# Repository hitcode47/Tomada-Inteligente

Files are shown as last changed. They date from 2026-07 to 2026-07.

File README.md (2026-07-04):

# EcoPlug — Tomada Inteligente

Projeto desenvolvido para a disciplina de **Projeto de Sistemas Embutidos** do Curso de Graduação em Engenharia Elétrica da **Universidade Federal de Minas Gerais (UFMG)**.

---

O consumo de energia elétrica residencial é, em grande parte, invisível ao usuário final: a conta de luz mostra apenas um valor mensal agregado, sem indicar quais aparelhos são responsáveis pela maior parcela do gasto. Essa falta de visibilidade dificulta a identificação de desperdícios e torna quase impossível tomar decisões conscientes sobre o uso da energia — como identificar um aparelho com consumo acima do esperado por mau funcionamento, ou simplesmente entender como hábitos do dia a dia se traduzem em custo.

O **EcoPlug** foi criado para preencher essa lacuna. Trata-se de uma tomada inteligente que, ao ser inserida entre a tomada da parede e o aparelho, passa a medir continuamente tensão, corrente, potência ativa e energia acumulada — com erro inferior a 5%. Esses dados são enviados a cada 5 segundos para um servidor em nuvem e exibidos em tempo real em uma interface web acessível de qualquer dispositivo na rede.

Além do monitoramento, o sistema permite ligar e desligar remotamente a tomada, registra o histórico de consumo por hora, gera gráficos de potência e estimativa de custo em reais, e sinaliza o estado do dispositivo por LEDs indicadores. O protótipo suporta múltiplas tomadas monitoradas simultaneamente e é configurado via portal Wi-Fi, sem necessidade de programação pelo usuário final.

O hardware foi desenvolvido em torno de um ESP32, com o módulo PZEM-004T para medição elétrica, relé para controle do acionamento e um invólucro impresso em 3D. O backend roda em FastAPI com banco de dados PostgreSQL hospedado na Oracle Cloud, e o frontend foi desenvolvido em React.

## Project Model Canvas

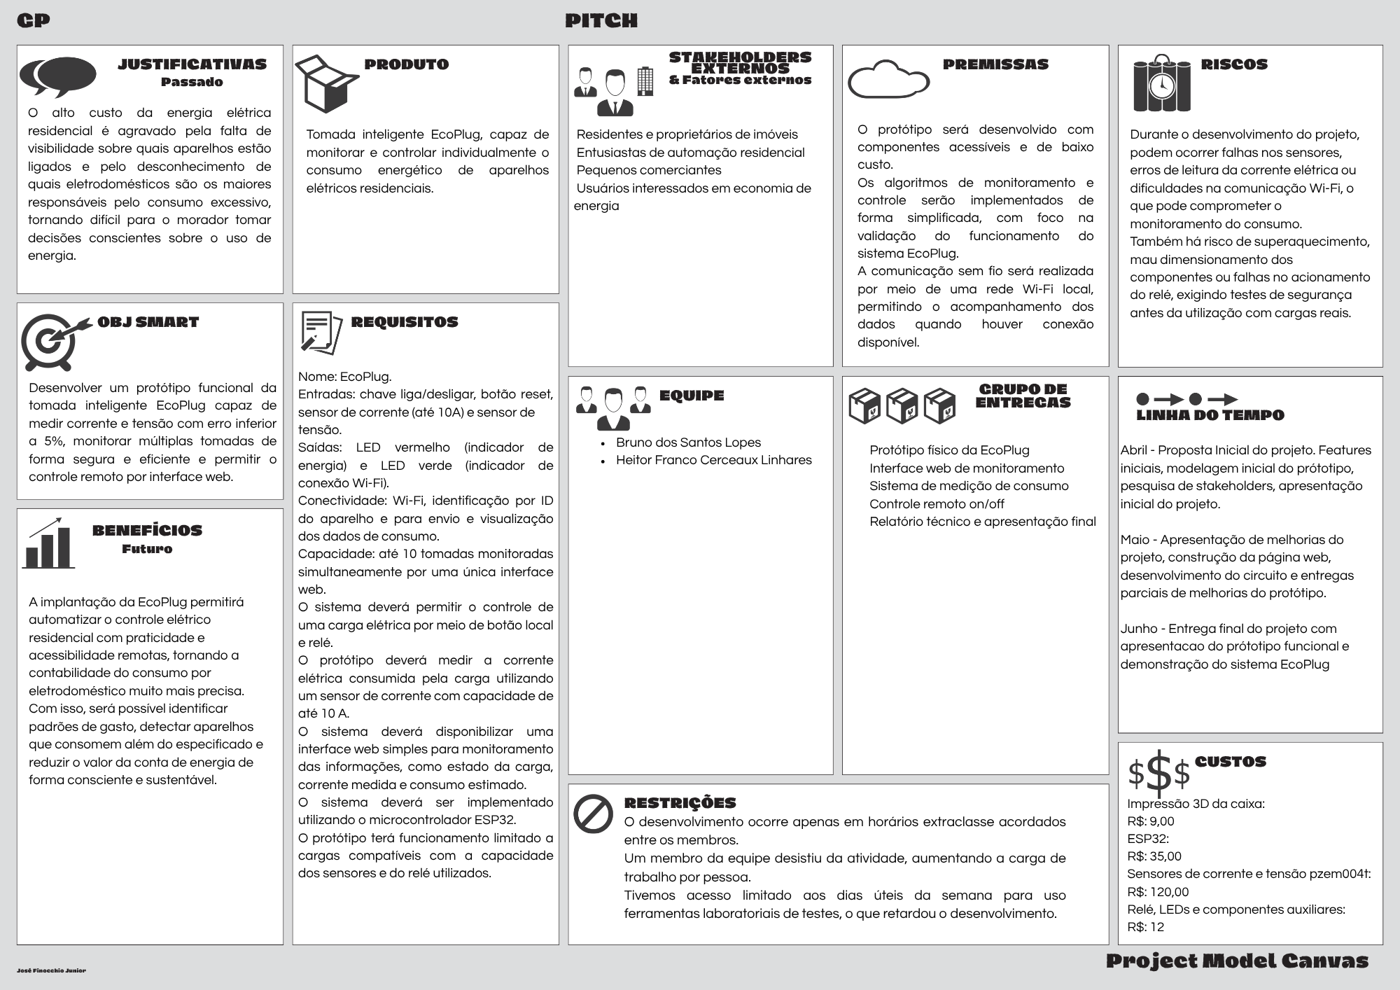
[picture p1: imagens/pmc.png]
Project Model Canvas


## Imagens

| | |
|---|---|
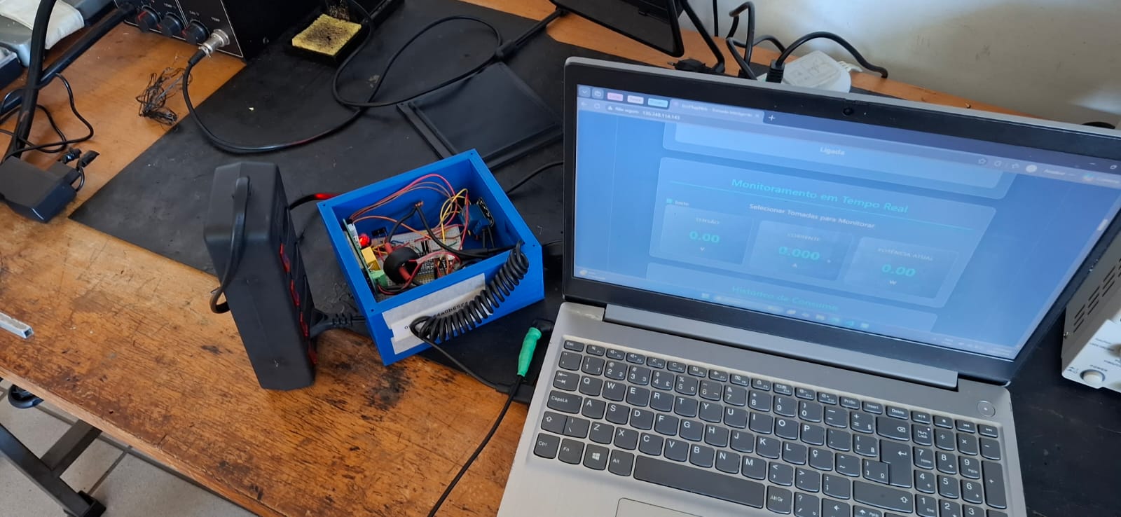
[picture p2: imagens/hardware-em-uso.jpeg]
Hardware em uso
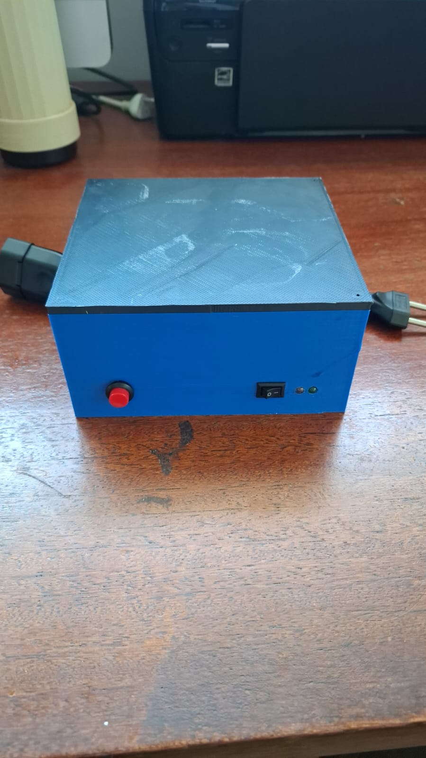
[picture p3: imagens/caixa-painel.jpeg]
Painel frontal
|  |  |
| Protótipo em bancada com dashboard no navegador | Painel frontal: botão de reset, chave e LEDs de status |
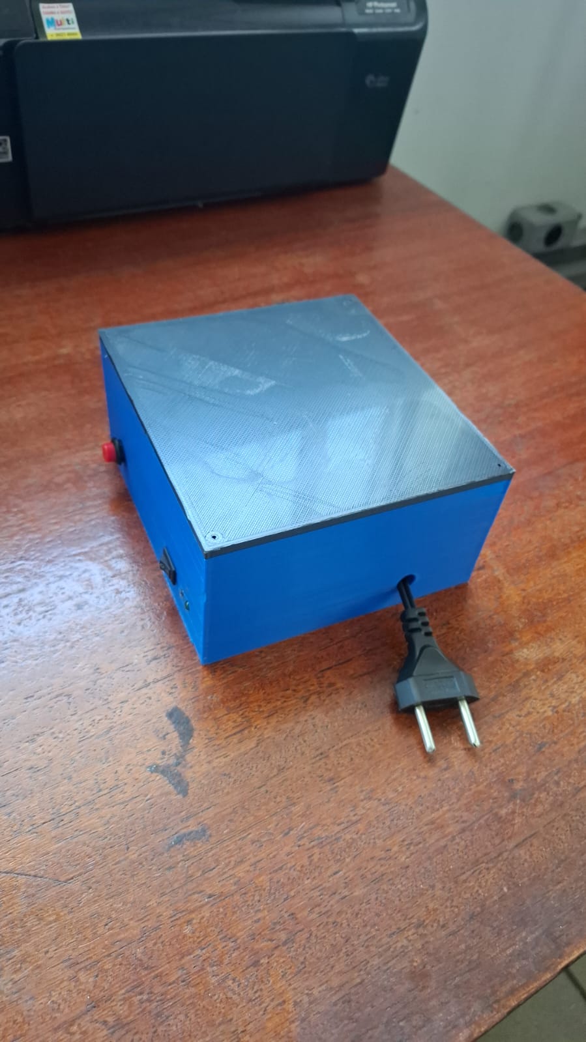
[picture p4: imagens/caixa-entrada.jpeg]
Entrada AC
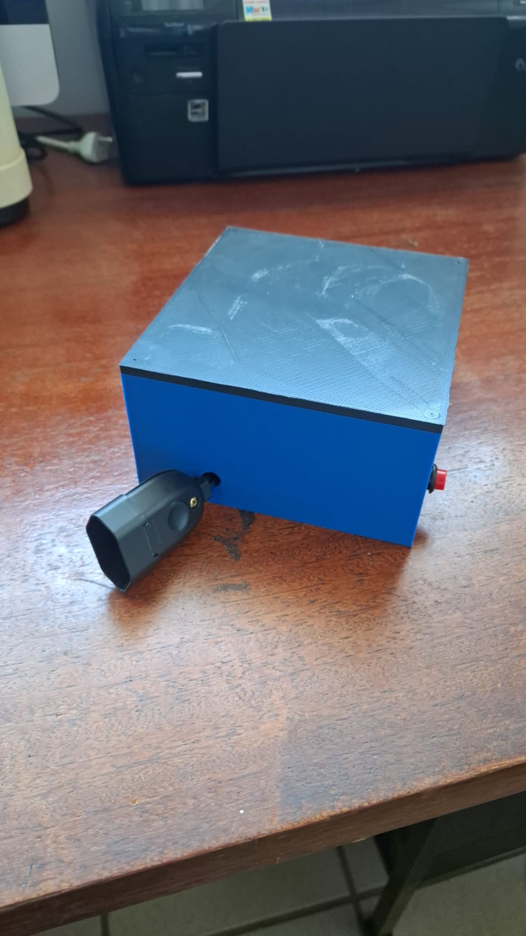
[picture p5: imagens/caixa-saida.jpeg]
Saída AC
|  |  |
| Caixa fechada — entrada de energia (plug macho) | Lateral com tomada de saída (fêmea) |

### Esquemático elétrico

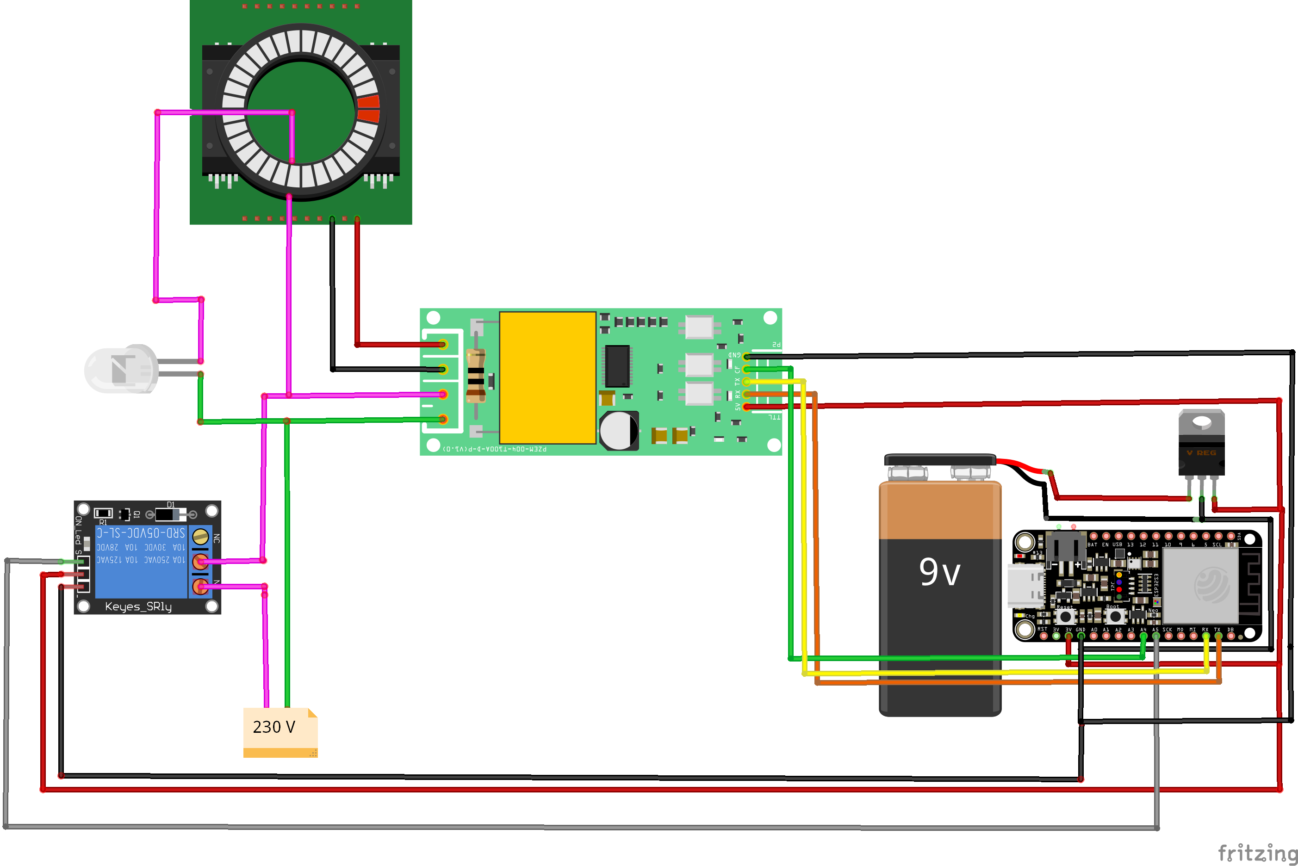
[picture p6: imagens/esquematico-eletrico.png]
Esquemático elétrico


## Arquitetura

```
┌──────────────────────────────────────────────────┐
│              Hardware (ESP32 + PZEM-004T)        │
│   - Mede tensão, corrente, potência, energia     │
│   - WiFi Enterprise (WPA2-EAP / UFMG)           │
│   - Relé NC para controle da tomada             │
└──────────────────┬───────────────────────────────┘
                   │ POST JSON a cada 5s
                   ↓
┌──────────────────────────────────────────────────┐
│         Backend (FastAPI + PostgreSQL)           │
│   - Armazena leituras no banco de dados         │
│   - Autenticação JWT                            │
│   - API REST: energia, dispositivos, gráficos   │
└──────────────────┬───────────────────────────────┘
                   │ GET JSON (polling 5s)
                   ↓
┌──────────────────────────────────────────────────┐
│         Frontend (React + Vite)                  │
│   - Dashboard em tempo real                     │
│   - Gráficos de consumo (potência / custo)      │
│   - Gerenciamento e controle de tomadas         │
└──────────────────────────────────────────────────┘
```

## Estrutura do Projeto

```
Tomada-Inteligente/
├── Backend/
│   ├── main.py                # Servidor FastAPI
│   ├── models.py              # Modelos SQLAlchemy
│   ├── schemas.py             # Schemas Pydantic
│   ├── database.py            # Conexão PostgreSQL
│   ├── security.py            # JWT e autenticação
│   ├── routers/
│   │   ├── auth.py            # Login / registro
│   │   ├── devices.py         # CRUD de dispositivos
│   │   └── energia.py         # Leituras e gráficos
│   ├── requirements.txt
│   └── .env.example
├── Frontend/
│   ├── src/
│   │   ├── components/
│   │   │   ├── Header.jsx
│   │   │   ├── ManagementSection.jsx
│   │   │   ├── ControlSection.jsx
│   │   │   ├── MonitoringSection.jsx
│   │   │   ├── ChartFilterSection.jsx
│   │   │   └── HistorySection.jsx
│   │   ├── pages/
│   │   │   ├── HomePage.jsx
│   │   │   └── LoginPage.jsx
│   │   ├── hooks/
│   │   │   └── useSockets.js
│   │   ├── services/
│   │   │   ├── socketService.js
│   │   │   └── authService.js
│   │   ├── config.js
│   │   ├── App.jsx
│   │   └── main.jsx
│   ├── .env.production
│   ├── package.json
│   └── vite.config.js
├── hardware/
│   └── controle.ino           # Firmware ESP32
├── imagens/                   # Screenshots e fotos do hardware
└── README.md
```

## Hardware

| Componente | Função |
|---|---|
| ESP32 | Controlador principal + WiFi |
| PZEM-004T | Medidor de tensão, corrente, potência e energia (com núcleo toroidal para leitura de corrente) |
| Relé NC | Controle da tomada (fail-safe: ligada sem energia no relé) |
| LED vermelho (GPIO 22) | Sistema energizado; pisca 3x no reset |
| LED verde (GPIO 23) | WiFi conectado |
| Botão (GPIO 5) | Reset de fábrica (segurar 5s) |

O circuito é montado dentro de um **invólucro impresso em 3D** (cor azul), com entrada de energia (plugue macho) e saída para o aparelho (tomada fêmea) expostos externamente. A eletrônica de controle é alimentada de forma autônoma, independente da carga monitorada.

**Especificações:**
- Tensão medida: 80–260 V CA
- Corrente máxima: 10 A (CT embutido do PZEM-004T)
- Amostragem interna do sensor: ~1 s
- Intervalo de envio ao servidor: 5 s
- Atualização da interface web: ~5 s (polling)
- Erro de medição: < 5%
- Conexão: WPA2-Enterprise (EAP-PEAP) — compatível com redes institucionais (UFMG/Eduroam)

## Configuração do Hardware

1. Ligar o ESP32 pela primeira vez
2. Conectar ao AP `Tomada-Setup` (senha: `12345678`)
3. Acessar `http://192.168.4.1`
4. Preencher SSID, usuário e senha da rede
5. O dispositivo reinicia e começa a enviar dados

Para redefinir as credenciais: segurar o botão de reset por 5 segundos.

## Configuração do Backend

```bash
cd Backend
cp .env.example .env      # preencher DATABASE_URL e SECRET_KEY
pip install -r requirements.txt
uvicorn main:app --host 0.0.0.0 --port 5000
```

## Configuração do Frontend

```bash
cd Frontend
npm install
# Desenvolvimento
npm run dev

# Produção
npm run build             # gera dist/
```

Editar `Frontend/.env.production` para apontar para o servidor:

```env
VITE_API_BASE_URL=http://seu-servidor:5000
```

## Deploy (Produção)

O backend roda em Oracle Cloud (Ubuntu 22.04) com FastAPI + Uvicorn gerenciado pelo systemd e nginx como proxy reverso. O frontend é servido como site estático pelo nginx.

## Endpoints principais da API

| Método | Rota | Descrição |
|---|---|---|
| POST | `/api/auth/register` | Cadastro de usuário |
| POST | `/api/auth/login` | Login (retorna JWT) |
| GET | `/api/devices/` | Listar dispositivos |
| POST | `/api/devices/claim` | Vincular dispositivo |
| PATCH | `/api/devices/{serial}` | Renomear dispositivo |
| DELETE | `/api/devices/{serial}` | Desvincular dispositivo |
| POST | `/api/devices/{serial}/relay` | Acionar relé |
| POST | `/api/energia/{serial}` | Receber leitura do ESP32 |
| GET | `/api/energia/{serial}` | Última leitura |
| GET | `/api/energia/{serial}/chart` | Dados para gráfico |

## Próximos Passos

- [x] Gráfico de custo em reais por período (já implementado na interface)
- [ ] Validação com múltiplas tomadas operando simultaneamente em campo
- [ ] Alertas por e-mail quando consumo exceder limite configurado
- [ ] Autenticação do dispositivo com token fixo no header HTTP
- [ ] Exportar histórico de consumo em CSV
- [ ] Suporte a WPA2 pessoal (além de Enterprise) no portal de configuração
- [ ] App mobile (React Native ou PWA)

## Autores

- Bruno dos Santos Lopes
- Heitor Franco Cerceaux Linhares

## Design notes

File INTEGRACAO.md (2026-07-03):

# Tomada Inteligente - Guia de Integração

## Arquitetura

```
ESP32 (Hardware)
    ↓ (POST JSON)
Backend Flask (Python)
    ↓ (HTTP GET)
Frontend React (JavaScript)
    ↓ (Controle de UI)
Navegador
```

## Instruções para Executar

### 1. Backend Flask

```bash
# Navegar até a pasta Backend
cd Backend

# Instalar dependências
pip install -r requirements.txt

# Executar o servidor
python app.py
```

O backend estará disponível em: `http://localhost:5000`

**Endpoints disponíveis:**
- `POST /api/energia/<serial_number>` - Receber dados do ESP32
- `GET /api/energia/<serial_number>` - Último registro
- `GET /api/energia/<serial_number>/history` - Histórico de registros

### 2. Frontend React

```bash
# Navegar até a pasta Frontend
cd Frontend

# Instalar dependências (se não estiver feito)
npm install

# Modo desenvolvimento
npm run dev

# Ou build para produção
npm run build
```

O frontend estará disponível em: `http://localhost:5173` (ou a porta indicada pelo Vite)

**Variáveis de ambiente:**
- `VITE_API_BASE_URL` - URL da API (padrão: `http://localhost:5000`)

Editar `.env` para mudar o servidor:
```
VITE_API_BASE_URL=http://seu-ip:5000
```

### 3. Testar com Dados Simulados

```bash
# Na pasta Backend, em outro terminal
python test_backend.py
```

Este script:
- ✓ Popula o histórico com 10 registros por socket
- ✓ Envia dados simulados a cada 5 segundos
- ✓ Exibe o histórico no console

### 4. Configurar Hardware ESP32

Editar o arquivo `.ino` e atualizar:
```cpp
serverUrl = "http://<seu-ip>:5000/api/energia/" + SERIAL_NUMBER;
```

Onde `<seu-ip>` é o IP da máquina rodando o Backend.

## Fluxo de Dados

### Hardware → Backend
O ESP32 envia dados via `POST`:
```json
{
  "voltage": 230.5,
  "current": 1.25,
  "power": 288.1,
  "frequency": 60.0,
  "pf": 0.95
}
```

### Backend → Frontend
O Frontend faz polling a cada 5 segundos (configurável em `src/config.js`):
```json
{
  "serial_number": "test-socket-01",
  "received_at": "2026-05-16T10:30:45.123Z",
  "voltage": 230.5,
  "current": 1.25,
  "power": 288.1,
  "frequency": 60.0,
  "pf": 0.95
}
```

## Troubleshooting

**Frontend não conecta ao Backend:**
- Verificar se o Backend está rodando em `http://localhost:5000`
- Atualizar `.env` com o IP correto
- Limpar cache do navegador (Ctrl+Shift+Del)

**Erro CORS:**
- O Backend já tem CORS configurado para aceitar requisições de qualquer origem
- Se ainda houver erro, editar `app.py` e adicionar `@app.after_request`

**ESP32 não envia dados:**
- Verificar se a conexão WiFi está estável
- Verificar se o IP do backend está correto
- Testar com `curl` do computador

**Dados antigos no histórico:**
- O histórico fica na memória do Backend enquanto estiver rodando
- Reiniciar o Backend para limpar histórico
- Para persistência, adicionar banco de dados (SQLite/PostgreSQL)

## Próximos Passos

- [ ] Implementar autenticação (JWT/OAuth)
- [ ] Adicionar banco de dados para persistência
- [ ] Webocket para atualização em tempo real
- [ ] Dashboard com gráficos avançados
- [ ] Alertas e notificações
- [ ] Controle de tomadas (ON/OFF)

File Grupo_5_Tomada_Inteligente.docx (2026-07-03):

# UNIVERSIDADE FEDERAL DE MINAS GERAIS

Escola de Engenharia

Curso de Graduação em Engenharia Elétrica

Projeto de Sistemas Embutidos

##### EcoPlug

##### Tomada Inteligente

DESENVOLVIDO PELA EQUIPE:

Heitor Franco Cerceaux Linhares

Bruno dos Santos Lopes

Data de entrega 02/07/2026

# 1. introdução

O consumo de energia elétrica residencial é, em grande parte, invisível ao usuário final: a conta de luz mostra apenas um valor mensal agregado, sem indicar quais aparelhos são responsáveis pela maior parcela do gasto. Essa falta de visibilidade dificulta a identificação de desperdícios e a tomada de decisões conscientes sobre o uso da energia em casa.

Para enfrentar esse problema, nós desenvolvemos o EcoPlug, uma tomada inteligente capaz de medir tensão e corrente em tempo real, calcular a potência e o consumo acumulado de um aparelho conectado a ela, e disponibilizar essas informações ao usuário por meio de uma interface web. O sistema também permite o controle remoto do acionamento da tomada (ligar/desligar) e sinaliza seu estado por meio de LEDs indicadores.

Este relatório documenta o desenvolvimento do protótipo do EcoPlug ao longo do semestre da disciplina de Projeto de Sistemas Embutidos, apresentando a justificativa do projeto, o objetivo definido para o protótipo, a especificação de requisitos, o diagrama geral do sistema, o desenvolvimento do hardware e da interface de monitoramento, as premissas, restrições e riscos identificados, os benefícios esperados e as considerações finais sobre o trabalho realizado.

# 2. justificativa

O alto custo da energia elétrica residencial é agravado pela falta de visibilidade sobre quais aparelhos estão ligados e pelo desconhecimento de quais eletrodomésticos são os maiores responsáveis pelo consumo excessivo, tornando difícil tomar decisões conscientes sobre o uso de energia.

Sem uma ferramenta de acompanhamento individualizado por tomada, o consumidor não consegue relacionar hábitos de uso a variações na conta de luz, nem identificar aparelhos com consumo acima do esperado (por exemplo, por mau funcionamento ou uso indevido). O EcoPlug propõe-se a preencher essa lacuna, transformando dados elétricos que normalmente são invisíveis no dia a dia em informações acessíveis, organizadas por tags e apresentadas de forma contínua em um aplicativo web.

# 3. objetivo do projeto

Desenvolver um protótipo funcional da tomada inteligente EcoPlug capaz de medir corrente e tensão com erro inferior a 5%, monitorar até 10 tomadas de forma segura e eficiente e permitir o controle remoto por interface web.

Esse objetivo foi definido seguindo o critério SMART: específico (mede corrente, tensão e controla o acionamento), mensurável, alcançável e realista dentro dos recursos e do prazo da disciplina, e delimitado no tempo pelo cronograma do semestre letivo.

# 4. especificação de requisitos

Os requisitos do produto foram definidos com base no modelo de requisitos adotado na disciplina, são eles:

Nome | EcoPlug
Propósito | Gerenciamento e controle de gastos energéticos residenciais, por meio do monitoramento e controle individual do consumo de aparelhos elétricos.
Entradas | Chave liga/desliga; botão de reset; sensor de corrente (até 10 A); sensor de tensão.
Saídas | LED vermelho – indicador de energia (ligado/desligado); LED verde – indicador de conexão Wi-Fi (ativo/inativo); acionamento do relé de controle da carga.
Funções | Histórico e gráfico de consumo; comparação e alerta de consumo; controle de acionamento remoto; identificação do aparelho por ID; organização por tags.
Desempenho | Medição ativa apenas com carga conectada; taxa de amostragem local de 1 s; atualização da interface web a cada 15 s; erro de medição inferior a 5%; até 5 tomadas monitoradas simultaneamente por uma única interface web.
Conectividade | Comunicação Wi-Fi entre a tomada e o servidor/nuvem responsável pelo processamento e armazenamento dos dados.
Custo de manufatura | Em torno de R$ 176,00 o protótipo. Impressão 3D da caixa: R$: 9,00 ESP32: R$: 35,00 Sensores de corrente e tensão pzem004t: R$: 120,00 Relé, LEDs e componentes auxiliares: R$: 12
Potência | Compatível com aparelhos residenciais de uso comum, respeitando o limite de corrente de 10 A do sensor utilizado.
Dimensões físicas | Aproximadamente 5 x 7 x 10 cm; massa aproximada de 300 g.

# 5. diagrama geral do sistema

A Figura a seguir apresenta a arquitetura geral do EcoPlug, dividida em três camadas: o hardware da tomada inteligente (entradas de sensoriamento, processamento embarcado e saídas de controle/indicação), o servidor/nuvem responsável pelo armazenamento e processamento dos dados e pelo cálculo de consumo em reais, e a interface do usuário (aplicativo web), onde são exibidos gráficos, histórico, alertas e a organização dos dispositivos por tags.

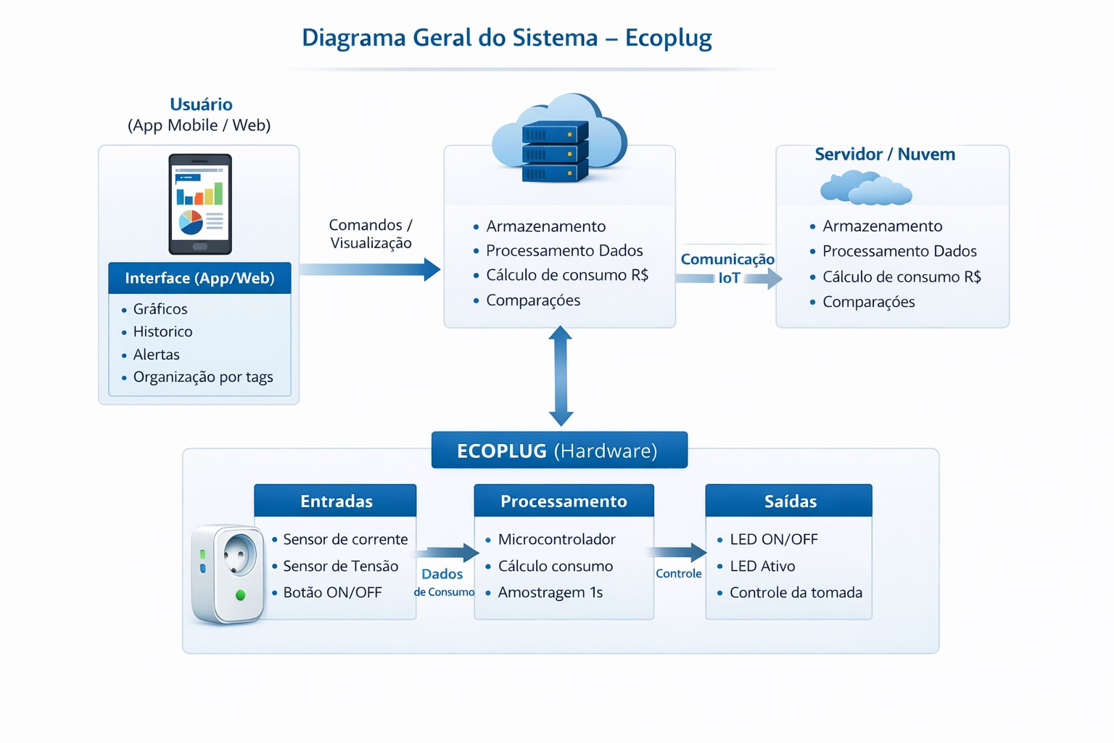
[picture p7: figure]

Figura - 1 – Diagrama geral do sistema EcoPlug, com as camadas de hardware, servidor/nuvem e interface do usuário.

No hardware, o microcontrolador lê continuamente o sensor de corrente e o sensor de tensão, amostrados localmente a cada 1s aproximadamente, calcula o consumo instantâneo e envia esses dados para o servidor a cada ciclo de comunicação. O servidor, por sua vez, armazena o histórico, calcula o custo em reais e disponibiliza os dados para a interface web, que é atualizada a cada 10s aproximadamente. O sentido inverso do fluxo, comandos de ligar/desligar enviados pelo usuário, percorre o mesmo caminho até acionar o relé que controla a tomada.

# 6. desenvolvimento do protótipo

## 6.1 montagem do hardware

O protótipo foi montado em um invólucro impresso em 3D, na cor azul, dimensionado para acomodar todo o circuito de forma segura e isolada da rede elétrica externa. A Figura a seguir mostra o protótipo finalizado, já com a tampa fechada, o botão de acionamento (em vermelho) e o plugue de saída para a tomada.

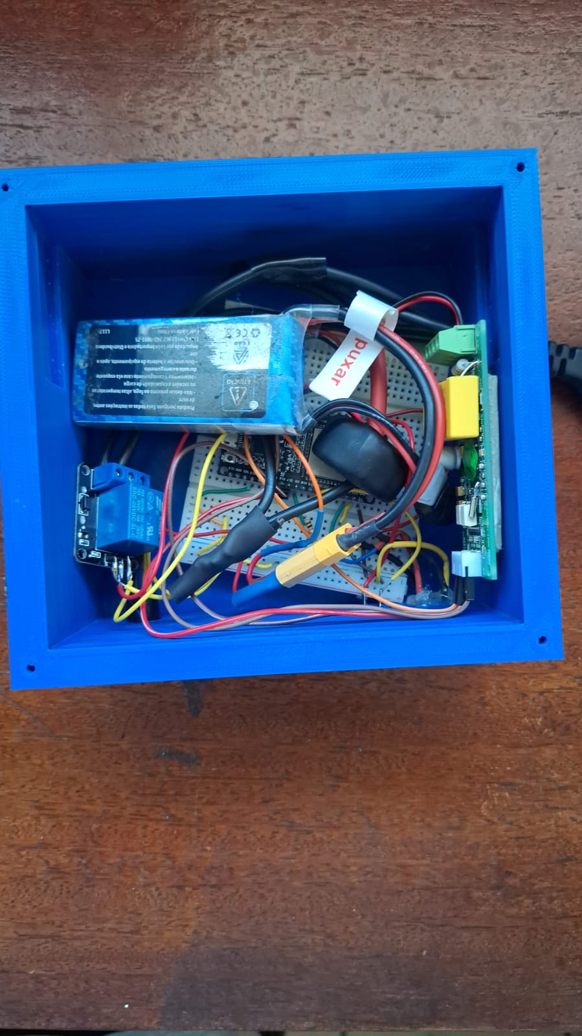
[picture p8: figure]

Figura - 2 – Vista externa (esquerda) e vista interna (direita) do protótipo do EcoPlug.

Internamente, o circuito foi montado em uma protoboard, concentrando o microcontrolador e o circuito de condicionamento de sinais dos sensores de corrente e de tensão. A alimentação autônoma do sistema é fornecida por uma bateria de Li-Po de 7V, permitindo que a eletrônica de controle continue operando de forma independente da carga monitorada. O acionamento da tomada é feito por um módulo relé, responsável por ligar e desligar fisicamente o aparelho conectado a partir dos comandos recebidos pelo microcontrolador. Um bloco de conexão (terminal) e um núcleo toroidal associado ao sensor de corrente completam o circuito de medição, enquanto a fiação foi organizada e protegida com termorretrátil nos pontos de maior risco de curto-circuito.

## 6.2 interface de monitoramento

A interface web do EcoPlug foi testada em conjunto com o protótipo, conectado a um computador na mesma rede que envia os dados para a nuvem da Oracle para o armazenamento no banco de dados e envia para o usuário. A tela de monitoramento do cliente exibe, em tempo real, os valores de tensão, corrente e potência atual da tomada selecionada, além do histórico de consumo, permitindo ao usuário selecionar qual tomada deseja acompanhar e visualizar o estado de acionamento (ligada/desligada).


Figura - 3 – Bancada de testes: protótipo do EcoPlug conectado e interface web de monitoramento em tempo real.

Durante os testes de bancada, a tomada foi conectada sem carga, estávamos fazendo o carregamento do código no microcontrolador motivo pelo qual os campos de tensão, corrente e potência aparecem zerados na Figura 4; a leitura dos sensores só é ativada quando há um aparelho efetivamente conectado e quando a controladora esta ligada, conforme especificado no requisito de desempenho do sistema.

# 7. premissas e restrições

Premissas assumidas pela equipe para o planejamento do projeto:

– Os integrantes terão disponibilidade regular para reuniões e desenvolvimento ao longo do semestre.

– Os componentes eletrônicos necessários estarão disponíveis para compra dentro do orçamento do grupo.

– A rede Wi-Fi do laboratório permitirá testes de conectividade.

– O professor orientará dúvidas técnicas quando necessário.

Restrições impostas ao desenvolvimento do projeto:

– O projeto deve ser concluído até o final do semestre letivo.

– O orçamento é limitado ao valor disponibilizado pelo grupo, sem patrocínio externo.

– O desenvolvimento ocorre apenas nos horários de aula e em encontros extraclasse acordados entre os membros.

– O protótipo deve ser construído com componentes acessíveis no mercado nacional.

# 8. benefícios esperados

Com a implantação do EcoPlug, espera-se automatizar o controle elétrico residencial remotamente, tornando o monitoramento do consumo por aparelho mais preciso. A ferramenta deve permitir identificar padrões de gasto, detectar aparelhos que consomem além do especificado e, com isso, contribuir para a redução da conta de energia do usuário.

# 9. considerações finais

O desenvolvimento do EcoPlug permitiu à equipe aplicar, em um projeto, os conceitos de sistemas embarcados trabalhados ao longo da disciplina, desde a especificação de requisitos e o projeto do diagrama geral do sistema até a montagem do hardware e a integração com uma interface de monitoramento web. O protótipo construído demonstra, em escala reduzida, a viabilidade de uma tomada inteligente capaz de medir e controlar remotamente o consumo de um aparelho residencial.

Como trabalhos futuros, destacam-se um melhor gráfico de custo por tempo dando o valor bruto gasto em reais, a validação do sistema com múltiplas tomadas operando simultaneamente, a consolidação da interface web com os recursos de alerta e comparação de consumo previstos nos requisitos do projeto.

Tomada Inteligente Página 2

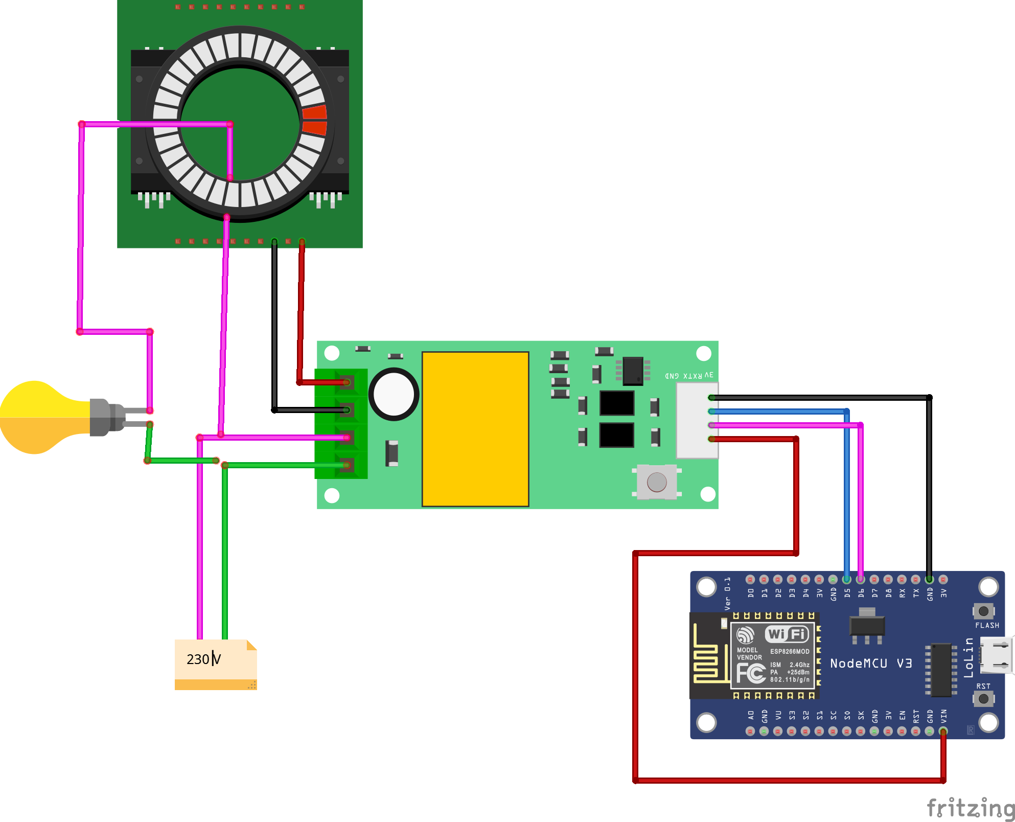
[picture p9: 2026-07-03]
hardware/Untitled Sketch_bb.png

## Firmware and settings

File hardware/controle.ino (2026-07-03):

#include <WiFi.h>
#include <HTTPClient.h>
#include <WebServer.h>
#include <Preferences.h>
#include <PZEM004Tv30.h>
#include <ArduinoOTA.h>
#include "esp_eap_client.h"
#include "esp_wifi.h"

// ======================
// Configuração
// ======================
#define SERVER_BASE_URL    "http://136.248.114.143:5000"
#define AP_SSID            "Tomada-Setup"
#define AP_PASS            "12345678"
#define PZEM_RX            16
#define PZEM_TX            17
#define RELAY_PIN          15
#define RESET_BTN_PIN      5    // ativo em LOW
#define LED_PIN            22   // vermelho: sistema ligado / pisca no reset
#define LED_GREEN_PIN      23   // verde: WiFi conectado
#define CONNECT_TIMEOUT_S  309
#define HTTP_TIMEOUT_MS    8000
#define SEND_INTERVAL_MS   5000

// ======================
// Objetos
// ======================
WebServer      server(80);
Preferences    prefs;
HardwareSerial pzemSerial(1);
PZEM004Tv30*   pzem = nullptr;   // inicializado em setup(), evita construtor antes de Serial.begin()

// ======================
// Estado
// ======================
String wifiSSID, loginUFMG, senhaUFMG, serverBase;
String SERIAL_NUMBER, serverUrl;
float  VOLTAGE, CURRENT, POWER, ENERGY, FREQ, PF;
bool   relayOn = false;

// ======================
// Utilitários
// ======================
float zeroIfNan(float v) {
  return (isnan(v) || isinf(v) || v > 1e6f) ? 0.0f : v;
}

// Garante serial sempre com 16 chars hex (zero-padded)
String fmtHex32(uint32_t v) {
  char buf[9];
  snprintf(buf, sizeof(buf), "%08lx", (unsigned long)v);
  return String(buf);
}

// ======================
// Portal de configuração
// ======================
void handleRoot() {
  String html = R"rawliteral(
<!DOCTYPE html><html>
<body style='font-family:Arial;padding:20px'>
  <h2>Configuração WiFi Enterprise</h2>
  <div style='background:#f0f0f0;padding:12px;border-radius:8px;margin-bottom:20px'>
    <p style='margin:0 0 4px;font-size:13px;color:#555'>Serial do dispositivo</p>
    <p style='margin:0;font-size:22px;font-weight:bold;letter-spacing:3px;font-family:monospace'>)rawliteral"
  + SERIAL_NUMBER +
  R"rawliteral(</p>
    <p style='margin:6px 0 0;font-size:12px;color:#888'>Anote este código para vincular o dispositivo ao seu app.</p>
  </div>
  <form action="/save" method="POST">
    SSID:<br><input name="ssid" style='width:100%;padding:6px;margin:4px 0 12px'><br>
    Usuário UFMG:<br><input name="login" style='width:100%;padding:6px;margin:4px 0 12px'><br>
    Senha:<br><input name="senha" type="password" style='width:100%;padding:6px;margin:4px 0 12px'><br>
    URL do servidor:<br><input name="server" value=")rawliteral"
  + serverBase +
  R"rawliteral(" placeholder="http://IP:5000" style='width:100%;padding:6px;margin:4px 0 12px'><br>
    <input type="submit" value="Conectar" style='background:#2a7;color:#fff;padding:10px 24px;border:none;border-radius:4px;cursor:pointer'>
  </form>
  <hr style='margin:24px 0'>
  <form action="/reset" method="POST">
    <input type="submit" value="Apagar credenciais salvas"
      style='background:#c33;color:#fff;padding:8px 16px;border:none;border-radius:4px;cursor:pointer'>
  </form>
</body></html>
)rawliteral";
  server.send(200, "text/html", html);
}

void handleSave() {
  prefs.begin("wifi", false);
  prefs.putString("ssid",  server.arg("ssid"));
  prefs.putString("login", server.arg("login"));
  prefs.putString("senha", server.arg("senha"));
  String sv = server.arg("server");
  if (sv.length() > 0) prefs.putString("server", sv);
  prefs.end();
  server.send(200, "text/html", "<h2>Credenciais salvas! Reiniciando...</h2>");
  delay(2000);
  ESP.restart();
}

void handleReset() {
  prefs.begin("wifi", false);
  prefs.clear();
  prefs.end();
  server.send(200, "text/html", "<h2>Credenciais apagadas. Reiniciando...</h2>");
  delay(2000);
  ESP.restart();
}

void startConfigPortal() {
  Serial.println("\n[Portal] Iniciando portal de configuração...");
  Serial.printf("[Portal] Serial: %s\n", SERIAL_NUMBER.c_str());

  WiFi.softAP(AP_SSID, AP_PASS);
  Serial.printf("[Portal] Conecte ao WiFi '%s' e acesse http://%s\n",
    AP_SSID, WiFi.softAPIP().toString().c_str());

  server.on("/",      HTTP_GET,  handleRoot);
  server.on("/save",  HTTP_POST, handleSave);
  server.on("/reset", HTTP_POST, handleReset);
  server.begin();

  while (true) {
    server.handleClient();
    delay(10);
  }
}

// ======================
// Servidor de config (operação normal)
// ======================
void startNormalWebServer() {
  server.on("/", HTTP_GET, []() {
    String html = "<html><body style='font-family:Arial;padding:20px'>"
      "<h2>EcoPlug — " + SERIAL_NUMBER + "</h2>"
      "<p>Servidor atual: <b>" + serverBase + "</b></p>"
      "<form action='/server' method='POST'>"
      "Nova URL:<br>"
      "<input name='server' value='" + serverBase + "' style='width:300px;padding:6px;margin:6px 0'><br>"
      "<input type='submit' value='Atualizar' style='background:#2a7;color:#fff;padding:8px 20px;border:none;border-radius:4px;cursor:pointer'>"
      "</form></body></html>";
    server.send(200, "text/html", html);
  });

  server.on("/server", HTTP_POST, []() {
    String sv = server.arg("server");
    if (sv.length() > 0) {
      prefs.begin("wifi", false);
      prefs.putString("server", sv);
      prefs.end();
      serverBase = sv;
      serverUrl  = serverBase + "/api/energia/" + SERIAL_NUMBER;
      Serial.printf("[Config] URL atualizada: %s\n", serverBase.c_str());
      server.send(200, "text/html",
        "<html><body style='font-family:Arial;padding:20px'>"
        "<h2>URL atualizada!</h2><p>" + serverBase + "</p>"
        "<a href='/'>Voltar</a></body></html>");
    } else {
      server.send(400, "text/plain", "URL invalida");
    }
  });

  server.begin();
  Serial.printf("[Config] Acesse http://%s/ para alterar a URL do servidor\n",
    WiFi.localIP().toString().c_str());
}

// ======================
// Conexão Enterprise
// ======================
bool connectEnterpriseWiFi() {
  Serial.printf("[WiFi] Conectando a '%s'...\n", wifiSSID.c_str());

  WiFi.disconnect(true, true);
  delay(500);
  WiFi.mode(WIFI_STA);

  esp_eap_client_set_identity(
    (const unsigned char*)loginUFMG.c_str(), loginUFMG.length());
  esp_eap_client_set_username(
    (const unsigned char*)loginUFMG.c_str(), loginUFMG.length());
  esp_eap_client_set_password(
    (const unsigned char*)senhaUFMG.c_str(), senhaUFMG.length());

  esp_wifi_sta_enterprise_enable();
  WiFi.begin(wifiSSID.c_str());

  for (int i = 0; i < CONNECT_TIMEOUT_S; i++) {
    if (WiFi.status() == WL_CONNECTED) break;
    Serial.print(".");
    delay(1000);
  }
  Serial.println();

  if (WiFi.status() != WL_CONNECTED) {
    Serial.println("[WiFi] Falha na conexão.");
    return false;
  }

  Serial.println("[WiFi] Conectado!");
  Serial.printf("[WiFi] IP local  : %s\n", WiFi.localIP().toString().c_str());
  Serial.println("[WiFi] ====================================");
  Serial.printf("[WiFi] Serial do dispositivo: %s\n", SERIAL_NUMBER.c_str());
  Serial.println("[WiFi] Use o serial acima para vincular no app.");
  Serial.println("[WiFi] ====================================");
  return true;
}

// ======================
// OTA (upload via WiFi)
// ======================
void setupOTA() {
  ArduinoOTA.setHostname(("tomada-" + SERIAL_NUMBER.substring(8)).c_str());
  ArduinoOTA.setPassword("ecoplug");   // senha exigida no upload OTA

  ArduinoOTA.onStart([]() {
    Serial.println("[OTA] Iniciando upload...");
  });
  ArduinoOTA.onEnd([]() {
    Serial.println("\n[OTA] Concluído. Reiniciando.");
  });
  ArduinoOTA.onProgress([](unsigned int progress, unsigned int total) {
    Serial.printf("[OTA] %u%%\r", progress * 100 / total);
  });
  ArduinoOTA.onError([](ota_error_t error) {
    Serial.printf("[OTA] Erro %u\n", error);
  });

  ArduinoOTA.begin();
  Serial.printf("[OTA] Pronto. Hostname: %s\n", ArduinoOTA.getHostname().c_str());
}

// ======================
// Reset por botão (segurar 5s)
// ======================
void checkResetButton() {
  static unsigned long pressStart = 0;
  static bool          wasPressed = false;

  bool pressed = (digitalRead(RESET_BTN_PIN) == LOW);

  if (pressed && !wasPressed) {
    pressStart = millis();
    wasPressed = true;
  } else if (!pressed) {
    wasPressed = false;
    pressStart = 0;
  } else if (pressed && (millis() - pressStart >= 5000)) {
    Serial.println("[Reset] Botão segurado 5s — apagando credenciais...");

    for (int i = 0; i < 3; i++) {
      digitalWrite(LED_PIN, HIGH); delay(200);
      digitalWrite(LED_PIN, LOW);  delay(200);
    }

    prefs.begin("wifi", false);
    prefs.clear();
    prefs.end();

    Serial.println("[Reset] Pronto. Reiniciando no portal de configuração...");
    delay(500);
    ESP.restart();
  }
}

// ======================
// Leitura PZEM
// ======================
void readPZEM() {
  VOLTAGE = zeroIfNan(pzem->voltage());
  CURRENT = zeroIfNan(pzem->current());
  POWER   = zeroIfNan(pzem->power());
  ENERGY  = zeroIfNan(pzem->energy());   // Wh acumulado
  FREQ    = zeroIfNan(pzem->frequency());
  PF      = zeroIfNan(pzem->pf());

  if (VOLTAGE < 10.0f) {
    CURRENT = 0.0f;
    POWER   = 0.0f;
  }
}

void printPzem() {
  Serial.println("\n===== PZEM =====");
  Serial.printf("Voltage   : %.2f V\n",  VOLTAGE);
  Serial.printf("Current   : %.3f A\n",  CURRENT);
  Serial.printf("Power     : %.2f W\n",  POWER);
  Serial.printf("Energy    : %.0f Wh\n", ENERGY);
  Serial.printf("Frequency : %.1f Hz\n", FREQ);
  Serial.printf("PF        : %.2f\n",    PF);
  Serial.printf("Relay     : %s\n",      relayOn ? "ON" : "OFF");
  Serial.println("================");
}

// ======================
// Envio ao backend
// ======================
void sendData() {
  if (WiFi.status() != WL_CONNECTED) return;

  HTTPClient http;
  http.begin(serverUrl.c_str());
  http.addHeader("Content-Type", "application/json");
  http.setTimeout(HTTP_TIMEOUT_MS);

  char json[192];
  snprintf(json, sizeof(json),
    "{\"voltage\":%.2f,\"current\":%.3f,\"power\":%.2f,"
    "\"energy\":%.1f,\"frequency\":%.1f,\"pf\":%.2f}",
    VOLTAGE, CURRENT, POWER, ENERGY, FREQ, PF);

  int code = http.POST(json);

  if (code == HTTP_CODE_OK || code == HTTP_CODE_CREATED) {
    String payload = http.getString();
    bool newRelay = payload.indexOf("\"relay\":true") >= 0;
    if (newRelay != relayOn) {
      relayOn = newRelay;
      digitalWrite(RELAY_PIN, relayOn ? HIGH : LOW);
      prefs.begin("relay", false);
      prefs.putBool("state", relayOn);
      prefs.end();
    }
    Serial.printf("[HTTP] Enviado OK | Relay: %s\n", relayOn ? "ON" : "OFF");
  } else if (code < 0) {
    Serial.printf("[HTTP] Erro: %s\n", http.errorToString(code).c_str());
  } else {
    Serial.printf("[HTTP] Servidor retornou %d\n", code);
  }

  http.end();
}

// ======================
// Setup
// ======================
void setup() {
  Serial.begin(115200);
  delay(3000);

  // Serial number: MAC gravado em hardware, sempre 16 chars hex
  uint64_t mac = ESP.getEfuseMac();
  SERIAL_NUMBER = fmtHex32((uint32_t)(mac >> 32)) + fmtHex32((uint32_t)mac);

  Serial.println("\n==============================");
  Serial.printf("  Serial: %s\n", SERIAL_NUMBER.c_str());
  Serial.println("==============================\n");

  // Relay + LED + botão de reset
  pinMode(RELAY_PIN,     OUTPUT);
  pinMode(LED_PIN,       OUTPUT);
  pinMode(LED_GREEN_PIN, OUTPUT);
  pinMode(RESET_BTN_PIN, INPUT_PULLUP);
  digitalWrite(RELAY_PIN,    LOW);
  digitalWrite(LED_PIN,      HIGH); // vermelho sempre ligado (sistema ON)
  digitalWrite(LED_GREEN_PIN, LOW);

  // PZEM — inicializado aqui para que o construtor rode após Serial.begin()
  // O construtor chama pzemSerial.begin(9600) internamente
  pzem = new PZEM004Tv30(&pzemSerial, PZEM_RX, PZEM_TX);

  // Credenciais WiFi + URL do servidor
  prefs.begin("wifi", true);
  wifiSSID   = prefs.getString("ssid",   "");
  loginUFMG  = prefs.getString("login",  "");
  senhaUFMG  = prefs.getString("senha",  "");
  serverBase = prefs.getString("server", SERVER_BASE_URL);
  prefs.end();

  serverUrl = serverBase + "/api/energia/" + SERIAL_NUMBER;
  Serial.printf("[Config] Servidor: %s\n", serverBase.c_str());

  if (wifiSSID.isEmpty() || loginUFMG.isEmpty() || senhaUFMG.isEmpty()) {
    startConfigPortal();  // não retorna
  }

  if (!connectEnterpriseWiFi()) {
    Serial.println("[Setup] Reiniciando em 10s para nova tentativa...");
    delay(10000);
    ESP.restart();
  }
  digitalWrite(LED_GREEN_PIN, HIGH); // verde ON: WiFi conectado

  // Restaura estado do relé salvo antes de iniciar o loop
  prefs.begin("relay", true);
  relayOn = prefs.getBool("state", false);
  prefs.end();
  digitalWrite(RELAY_PIN, relayOn ? HIGH : LOW);
  Serial.printf("[Relay] Estado restaurado: %s\n", relayOn ? "ON" : "OFF");

  setupOTA();
  startNormalWebServer();
}

// ======================
// Loop
// ======================
void loop() {
  static unsigned long lastSend = 0;

  ArduinoOTA.handle();
  server.handleClient();
  checkResetButton();

  // Reconexão: reinicia o ESP em vez de ir ao portal (credenciais já salvas)
  if (WiFi.status() != WL_CONNECTED) {
    digitalWrite(LED_GREEN_PIN, LOW); // verde OFF: sem WiFi
    Serial.println("[WiFi] Conexão perdida. Reconectando...");
    if (!connectEnterpriseWiFi()) {
      Serial.println("[WiFi] Falha. Reiniciando em 10s...");
      delay(10000);
      ESP.restart();
    }
    digitalWrite(LED_GREEN_PIN, HIGH); // verde ON: reconectado
  }

  unsigned long now = millis();
  if (now - lastSend >= SEND_INTERVAL_MS) {
    lastSend = now;
    readPZEM();
    printPzem();
    sendData();
  }

  delay(10);  // cede CPU sem bloquear
}
